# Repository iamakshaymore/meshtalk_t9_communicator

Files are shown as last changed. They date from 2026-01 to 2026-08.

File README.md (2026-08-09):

<div align="center" markdown="1">

Meshtastic Logo
<h1>Meshtastic Firmware</h1>









</div>

</div>

<div align="center">
	<a href="https://meshtastic.org">Website</a>
	-
	<a href="https://meshtastic.org/docs/">Documentation</a>
</div>

## Overview

**This is a fork of the official Meshtastic firmware** with custom UI implementation currently working on:
- **Heltec WiFi LoRa 32 V3**
- **Heltec WiFi LoRa 32 V4**
- **MeshTalk T9** (Custom PCB - MESHTASTIC Build-Off 2026 Entry)

This fork adds a custom keyboard-driven UI with T9 input, LoRa network visualization, and message management capabilities using a 4x4 matrix keypad and TFT display.

### Hardware Configuration

#### Heltec V3 Custom Pin Configuration

**TFT Display (ST7789 240x320):**
- CS: GPIO 10
- DC: GPIO 11  
- RST: GPIO 12
- Backlight: GPIO 13
- SPI: VSPI (MOSI: 35, SCK: 36)

**4x4 Matrix Keypad:**
- Rows: GPIO 14, 15, 16, 17
- Cols: GPIO 4, 5, 6, 7

**Power & Battery:**
- VEXT Enable: GPIO 18 (active low)
- Battery Pin: GPIO 1 (ADC)
- ADC Channel: ADC_CHANNEL_0

#### Heltec V4 Custom Pin Configuration

**TFT Display (ST7789 240x320):**
- CS: GPIO 10
- DC: GPIO 11
- RST: GPIO 12  
- Backlight: GPIO 13
- SPI: VSPI (MOSI: 11, SCK: 14)

**4x4 Matrix Keypad:**
- Rows: GPIO 4, 5, 6, 7
- Cols: GPIO 15, 16, 17, 18

**Power & Battery:**
- VEXT Enable: GPIO 36 (active high, always on - powers GC1109 LDO)
- Battery Pin: GPIO 1 (ADC)
- ADC Channel: ADC_CHANNEL_0

#### MeshTalk T9 Custom Pin Configuration (MESHTASTIC Build-Off 2026 🏆)

**Hardware Platform:**
- **MCU:** ESP32-S3-WROOM-1-N16R8 (16MB Flash, 8MB PSRAM)
- **LoRa Module:** Seeed Wio-SX1262
- **Display:** ST7789 TFT (240x320) via LovyanGFX
- **Input:** 4x4 Matrix Keypad
- **Form Factor:** Custom PCB design with integrated components

**LoRa Configuration (Wio-SX1262):**
- MISO: GPIO 11
- MOSI: GPIO 12
- SCK: GPIO 13
- CS: GPIO 21
- Reset: GPIO 14
- DIO1: GPIO 9
- BUSY: GPIO 10
- RF Switch: DIO2 controlled
- TCXO: 1.8V

**Power & Battery:**
- Battery ADC: GPIO 8 (ADC_CHANNEL_7)
- ADC Control: GPIO 47 (enable/disable to save power)
- ADC Multiplier: 4.9 (390kΩ/10kΩ voltage divider)
- ADC Attenuation: 2.5dB
- Boot Button: GPIO 0 (hardware pull-up)

**Flash & Memory:**
- 16MB Flash (QIO mode, 80MHz)
- 8MB Octal SPI PSRAM (QIO OPI mode)
- Custom 16MB partition scheme

**Project Links:**
- 📁 Hardware Design: `meshtastic-build-off-2026/Hardware/meshtalk_t9/`
- 🎬 Demo Video: [YouTube](https://www.youtube.com/watch?v=elmYMMCQKS4)
- 📸 Photos & Schematics: `meshtastic-build-off-2026/Demo/`

### Features

- Custom T9 text input system for efficient messaging
- LoRa network node visualization with signal strength indicators
- Message management (send/receive/view history)
- Direct messaging and channel messaging support
- Favorites management
- Battery monitoring and power management
- Bluetooth disabled for reduced power consumption

## MESHTASTIC Build-Off 2026 Status 🏆

This project is my entry for the **MESHTASTIC Build-Off 2026** competition featuring the **MeshTalk T9** - a custom hardware device with integrated display and keypad.

### Phase 1: Custom PCB Design ✅ **COMPLETE**
- ✅ Designed custom PCB using **ESP32-S3-WROOM-1-N16R8** (16MB Flash, 8MB PSRAM)
- ✅ Integrated **Seeed Wio-SX1262** LoRa module
- ✅ Optimized board layout with RF considerations
- ✅ Integrated keypad matrix and display connections on-board
- ✅ Implemented power management with battery charging circuitry
- ✅ PCB manufactured and assembled successfully

### Phase 2: Firmware Adaptation ✅ **COMPLETE**
- ✅ Ported custom UI module to MeshTalk T9 hardware
- ✅ Updated pin configurations for custom PCB (`variants/esp32s3/meshtalk_t9/`)
- ✅ Configured SX1262 LoRa radio with proper RF switching
- ✅ Implemented battery monitoring with ADC control for power savings
- ✅ Created custom variant configuration with 16MB partition scheme
- ✅ Device boots and runs Meshtastic firmware successfully

### Phase 3: Testing & Validation ✅ **COMPLETE**
- ✅ Extensive testing similar to Heltec V3/V4 validation
- ✅ Range testing and mesh network performance benchmarks
- ✅ Power consumption analysis and optimization
- ✅ UI/UX testing with physical hardware
- ✅ Field testing in real-world scenarios
- ✅ Documentation and competition submission preparation

## Building the Firmware

### For Heltec V3 Custom
```bash
platformio run -e heltec-v3-custom
platformio run -e heltec-v3-custom -t upload
```

### For Heltec V4 Custom
```bash
platformio run -e heltec-v4-custom
platformio run -e heltec-v4-custom -t upload
```

### For MeshTalk T9 (Build-Off 2026 Entry)
```bash
# Build firmware
platformio run -e meshtalk-t9

# Upload to device
platformio run -e meshtalk-t9 -t upload --upload-port /dev/cu.usbmodem101

# Erase flash and upload (for first-time flash or troubleshooting)
platformio run -e meshtalk-t9 -t erase_upload

# Monitor serial output
platformio device monitor -p /dev/cu.usbmodem101
```

### Get Started

- 🔧 **[Original Meshtastic Firmware](https://github.com/meshtastic/firmware)** – Upstream repository
- 📖 **[Building Instructions](https://meshtastic.org/docs/development/firmware/build)** - Learn how to compile the firmware from source.
- ⚡ **[Flashing Instructions](https://meshtastic.org/docs/getting-started/flashing-firmware/)** - Install or update the firmware on your device.

Join the Meshtastic community and help improve the project! 🚀

## Stats

Repobeats analytics image

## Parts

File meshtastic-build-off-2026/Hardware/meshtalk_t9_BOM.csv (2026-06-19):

Reference | Qty | Value | DNP | Exclude from BOM | Exclude from Board | Footprint | Datasheet | Manufacturer | Description | MPN
C2 | 1 | 0.1uF |  |  |  | Capacitor_SMD:C_0805_2012Metric | ~ | YAGEO | Unpolarized capacitor, small symbol | CC0805KRX7R9BB104
C3 | 1 | 0.1uF |  |  |  | Capacitor_SMD:C_0805_2012Metric | ~ | YAGEO | Unpolarized capacitor, small symbol | CC0805KRX7R9BB104
C6 | 1 | 0.1uF |  |  |  | Capacitor_SMD:C_0805_2012Metric | ~ | YAGEO | Unpolarized capacitor, small symbol | CC0805KRX7R9BB104
R9 | 1 | 470 |  |  |  | Resistor_SMD:R_0805_2012Metric | ~ | YAGEO | Resistor, small symbol | RC0805FR-07470RL
R7 | 1 | 2k |  |  |  | Resistor_SMD:R_0805_2012Metric | ~ | YAGEO | Resistor, small symbol | RC0805FR-072KL
R2 | 1 | 5.1k |  |  |  | Resistor_SMD:R_0805_2012Metric | ~ | YAGEO | Resistor, small symbol | RC0805FR-075K1L
R3 | 1 | 5.1k |  |  |  | Resistor_SMD:R_0805_2012Metric | ~ | YAGEO | Resistor, small symbol | RC0805FR-075K1L
R1 | 1 | 10k |  |  |  | Resistor_SMD:R_0805_2012Metric | ~ | YAGEO | Resistor, small symbol | RC0805FR-0710KL
R10 | 1 | 10k |  |  |  | Resistor_SMD:R_0805_2012Metric | ~ | YAGEO | Resistor, small symbol | RC0805FR-0710KL
R11 | 1 | 10k |  |  |  | Resistor_SMD:R_0805_2012Metric | ~ | YAGEO | Resistor, small symbol | RC0805FR-0710KL
R4 | 1 | 100k |  |  |  | Resistor_SMD:R_0805_2012Metric | ~ | YAGEO | Resistor, small symbol | RC0805FR-07100KL
R6 | 1 | 100k |  |  |  | Resistor_SMD:R_0805_2012Metric | ~ | YAGEO | Resistor, small symbol | RC0805FR-07100KL
R8 | 1 | 100k |  |  |  | Resistor_SMD:R_0805_2012Metric | ~ | YAGEO | Resistor, small symbol | RC0805FR-07100KL
R5 | 1 | 390k |  |  |  | Resistor_SMD:R_0805_2012Metric | ~ | YAGEO | Resistor, small symbol | RC0805FR-07390KL
C1 | 1 | 10uF 16V X5R |  |  |  | Capacitor_SMD:C_0805_2012Metric | ~ | Samsung | Unpolarized capacitor, small symbol | CL21A106KOQNNNE
C4 | 1 | 10uF 16V X5R |  |  |  | Capacitor_SMD:C_0805_2012Metric | ~ | Samsung | Unpolarized capacitor, small symbol | CL21A106KOQNNNE
C5 | 1 | 10uF 16V X5R |  |  |  | Capacitor_SMD:C_0805_2012Metric | ~ | Samsung | Unpolarized capacitor, small symbol | CL21A106KOQNNNE
Q2 | 1 | 2N7002 |  |  |  | Package_TO_SOT_SMD:SOT-23 | https://www.onsemi.com/pub/Collateral/NDS7002A-D.PDF | Nexperia | 0.115A Id, 60V Vds, N-Channel MOSFET, SOT-23 | 2N7002,215
U5 | 1 | AP7361C-33E |  |  |  | Package_TO_SOT_SMD:SOT-223-3_TabPin2 | https://www.diodes.com/assets/Datasheets/AP7361C.pdf | Diodes Inc | 1A Low Dropout regulator, positive, 3.3V fixed output, SOT-223 | AP7361C-33E-13
J2 | 1 | Conn_01x02_Socket |  |  |  | Connector_Molex:Molex_PicoBlade_53261-0271_1x02-1MP_P1.25mm_Horizontal | ~ | Molex | Generic connector, single row, 01x02, script generated | 53261-0271
D1 | 1 | D_Schottky |  |  |  | Diode_SMD:D_SOD-123 | ~ | onsemi | Schottky diode | MBR0520LT1G
U1 | 1 | ESP32-S3-WROOM-1 |  |  |  | RF_Module:ESP32-S3-WROOM-1 | https://www.espressif.com/sites/default/files/documentation/esp32-s3-wroom-1_wroom-1u_datasheet_en.pdf | Espressif | RF Module, ESP32-S3 SoC, Wi-Fi 802.11b/g/n, Bluetooth, BLE, 32-bit, 3.3V, onboard antenna, SMD | ESP32-S3-WROOM-1-N16R16VA
D2 | 1 | LED |  |  |  | LED_SMD:LED_0805_2012Metric | ~ | Everlight | Light emitting diode | 17-215/GHC-YR1S2/3T
U3 | 1 | MCP73831-2-MC |  |  |  | Package_DFN_QFN:DFN-8-1EP_3x2mm_P0.5mm_EP1.7x1.4mm | http://ww1.microchip.com/downloads/en/DeviceDoc/20001984g.pdf | Microchip | Single cell, Li-Ion/Li-Po charge management controller, 4.20V, Tri-State Status Output, in DFN-8 package | MCP73831T-2ACI/MC
H1 | 1 | MountingHole |  | Excluded from BOM |  | MountingHole:MountingHole_2.2mm_M2 | ~ |  | Mounting Hole without connection
H2 | 1 | MountingHole |  | Excluded from BOM |  | MountingHole:MountingHole_2.2mm_M2 | ~ |  | Mounting Hole without connection
H3 | 1 | MountingHole |  | Excluded from BOM |  | MountingHole:MountingHole_2.2mm_M2 | ~ |  | Mounting Hole without connection
H4 | 1 | MountingHole |  | Excluded from BOM |  | MountingHole:MountingHole_2.2mm_M2 | ~ |  | Mounting Hole without connection
Q1 | 1 | Q_PMOS_GSD |  |  |  | Package_TO_SOT_SMD:SOT-23 | ~ | Alpha & Omega | P-MOSFET transistor, gate/source/drain | AO3401A
Q3 | 1 | Q_PMOS_GSD |  |  |  | Package_TO_SOT_SMD:SOT-23 | ~ | Alpha & Omega | P-MOSFET transistor, gate/source/drain | AO3401A
SW1 | 1 | SW_Push |  |  |  | Button_Switch_SMD:SW_Push_1P1T_NO_CK_KMR2 | ~ | HROparts | Push button switch, generic, two pins | KMR221G LFS
SW2 | 1 | SW_Push |  |  |  | Button_Switch_SMD:SW_SPST_Omron_B3FS-100xP | ~ | Omron | Push button switch, generic, two pins | B3FS-1002P
SW3 | 1 | SW_Push |  |  |  | Button_Switch_SMD:SW_SPST_Omron_B3FS-100xP | ~ | Omron | Push button switch, generic, two pins | B3FS-1002P
SW4 | 1 | SW_Push |  |  |  | Button_Switch_SMD:SW_SPST_Omron_B3FS-100xP | ~ | Omron | Push button switch, generic, two pins | B3FS-1002P
SW5 | 1 | SW_Push |  |  |  | Button_Switch_SMD:SW_SPST_Omron_B3FS-100xP | ~ | Omron | Push button switch, generic, two pins | B3FS-1002P
SW6 | 1 | SW_Push |  |  |  | Button_Switch_SMD:SW_SPST_Omron_B3FS-100xP | ~ | Omron | Push button switch, generic, two pins | B3FS-1002P
SW7 | 1 | SW_Push |  |  |  | Button_Switch_SMD:SW_SPST_Omron_B3FS-100xP | ~ | Omron | Push button switch, generic, two pins | B3FS-1002P
SW8 | 1 | SW_Push |  |  |  | Button_Switch_SMD:SW_SPST_Omron_B3FS-100xP | ~ | Omron | Push button switch, generic, two pins | B3FS-1002P
SW9 | 1 | SW_Push |  |  |  | Button_Switch_SMD:SW_SPST_Omron_B3FS-100xP | ~ | Omron | Push button switch, generic, two pins | B3FS-1002P
SW10 | 1 | SW_Push |  |  |  | Button_Switch_SMD:SW_SPST_Omron_B3FS-100xP | ~ | Omron | Push button switch, generic, two pins | B3FS-1002P
SW11 | 1 | SW_Push |  |  |  | Button_Switch_SMD:SW_SPST_Omron_B3FS-100xP | ~ | Omron | Push button switch, generic, two pins | B3FS-1002P
SW12 | 1 | SW_Push |  |  |  | Button_Switch_SMD:SW_SPST_Omron_B3FS-100xP | ~ | Omron | Push button switch, generic, two pins | B3FS-1002P
SW13 | 1 | SW_Push |  |  |  | Button_Switch_SMD:SW_SPST_Omron_B3FS-100xP | ~ | Omron | Push button switch, generic, two pins | B3FS-1002P
SW14 | 1 | SW_Push |  |  |  | Button_Switch_SMD:SW_SPST_Omron_B3FS-100xP | ~ | Omron | Push button switch, generic, two pins | B3FS-1002P
SW15 | 1 | SW_Push |  |  |  | Button_Switch_SMD:SW_SPST_Omron_B3FS-100xP | ~ | Omron | Push button switch, generic, two pins | B3FS-1002P
SW16 | 1 | SW_Push |  |  |  | Button_Switch_SMD:SW_SPST_Omron_B3FS-100xP | ~ | Omron | Push button switch, generic, two pins | B3FS-1002P
SW17 | 1 | SW_Push |  |  |  | Button_Switch_SMD:SW_SPST_Omron_B3FS-100xP | ~ | Omron | Push button switch, generic, two pins | B3FS-1002P
SW18 | 1 | SW_Push |  |  |  | Button_Switch_SMD:SW_Push_1P1T_NO_CK_KMR2 | ~ | HROparts | Push button switch, generic, two pins | KMR221G LFS
TP1 | 1 | TestPoint |  | Excluded from BOM |  | TestPoint:TestPoint_Pad_D1.0mm | ~ |  | test point
TP2 | 1 | TestPoint |  | Excluded from BOM |  | TestPoint:TestPoint_Pad_D1.0mm | ~ |  | test point
TP3 | 1 | TestPoint |  | Excluded from BOM |  | TestPoint:TestPoint_Pad_D1.0mm | ~ |  | test point
TP4 | 1 | TestPoint |  | Excluded from BOM |  | TestPoint:TestPoint_Pad_D1.0mm | ~ |  | test point
TP5 | 1 | TestPoint |  | Excluded from BOM |  | TestPoint:TestPoint_Pad_D1.0mm | ~ |  | test point
TP6 | 1 | TestPoint |  | Excluded from BOM |  | TestPoint:TestPoint_Pad_D1.0mm | ~ |  | test point
TP7 | 1 | TestPoint |  | Excluded from BOM |  | TestPoint:TestPoint_Pad_D1.0mm | ~ |  | test point
TP8 | 1 | TestPoint |  | Excluded from BOM |  | TestPoint:TestPoint_Pad_D1.0mm | ~ |  | test point
J1 | 1 | USB_C_Receptacle_USB2.0_16P |  |  |  | Connector_USB:USB_C_Receptacle_HRO_TYPE-C-31-M-12 | https://www.usb.org/sites/default/files/documents/usb_type-c.zip | HROparts | USB 2.0-only 16P Type-C Receptacle connector | TYPE-C-31-M-12
U2 | 1 | USBLC6-2SC6 |  |  |  | Package_TO_SOT_SMD:SOT-23-6 | https://www.st.com/resource/en/datasheet/usblc6-2.pdf | STMicroelectronics | Very low capacitance ESD protection diode, 2 data-line, SOT-23-6 | USBLC6-2SC6
U4 | 1 | Wio-SX1262 |  |  |  | Module:Wio SX1262 |  | SenseCAP |  | Wio-SX1262

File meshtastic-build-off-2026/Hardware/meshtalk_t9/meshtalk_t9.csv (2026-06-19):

Id | Designator | Footprint | Quantity | Designation | Supplier and ref
1 | R6,R4,R8 | R_0805_2012Metric | 3 | 100k
2 | U3 | DFN-8-1EP_3x2mm_P0.5mm_EP1.7x1.4mm | 1 | MCP73831-2-MC
3 | J1 | USB_C_Receptacle_HRO_TYPE-C-31-M-12 | 1 | USB_C_Receptacle_USB2.0_16P
4 | U2 | SOT-23-5 | 1 | AP2112K-3.3
5 | U4 | Wio SX1262 | 1 | Wio-SX1262
6 | R7 | R_0805_2012Metric | 1 | 2k
7 | SW1,SW3,SW14,SW12,SW9,SW2,SW17,SW13,SW10,SW7,SW16,SW6,SW8,SW4,SW11,SW5,SW15 | SW_SPST_Omron_B3FS-100xP | 17 | SW_Push
8 | D1 | D_SOD-123 | 1 | D_Schottky
9 | R3,R2 | R_0805_2012Metric | 2 | 5.1k
10 | U1 | ESP32-S3-WROOM-1 | 1 | ESP32-S3-WROOM-1
11 | C5,C4,C1 | C_0805_2012Metric | 3 | 10uF
12 | Q1,Q3 | SOT-23 | 2 | Q_PMOS_GSD
13 | R1 | R_0805_2012Metric | 1 | 10k
14 | C6,C2 | C_0805_2012Metric | 2 | 0.1uF
15 | C3 | C_0805_2012Metric | 1 | 0.1uf
16 | Q2 | SOT-23 | 1 | 2N7002
17 | R5 | R_0805_2012Metric | 1 | 390k
18 | J2 | Molex_PicoBlade_53261-0271_1x02-1MP_P1.25mm_Horizontal | 1 | Conn_01x02_Socket
19 | TP2,TP4,TP5,TP7,TP8,TP1,TP6,TP3 | TestPoint_Pad_D1.0mm | 8 | TestPoint

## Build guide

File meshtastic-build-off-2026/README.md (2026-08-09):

# MESHTASTIC Build-Off 2026 - Hardware Design

## Project Overview

This directory contains the custom hardware design for the **MESHTASTIC Build-Off 2026** competition entry. The goal is to create a custom PCB-based Meshtastic device with integrated display and keypad interface.

## PCB Renders

<table>
<tr>
<td width="50%">

**Front**

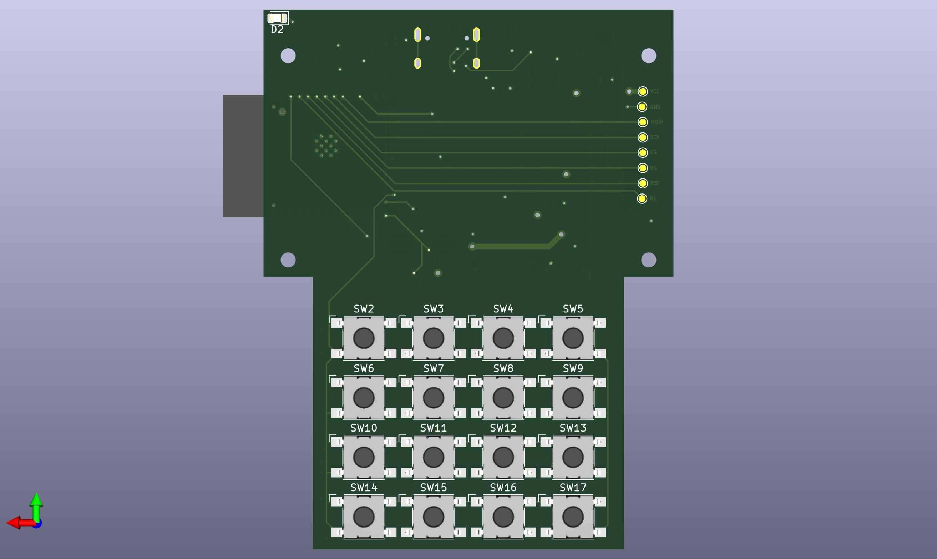
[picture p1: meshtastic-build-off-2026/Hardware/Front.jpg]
PCB Front Render


</td>
<td width="50%">

**Back**

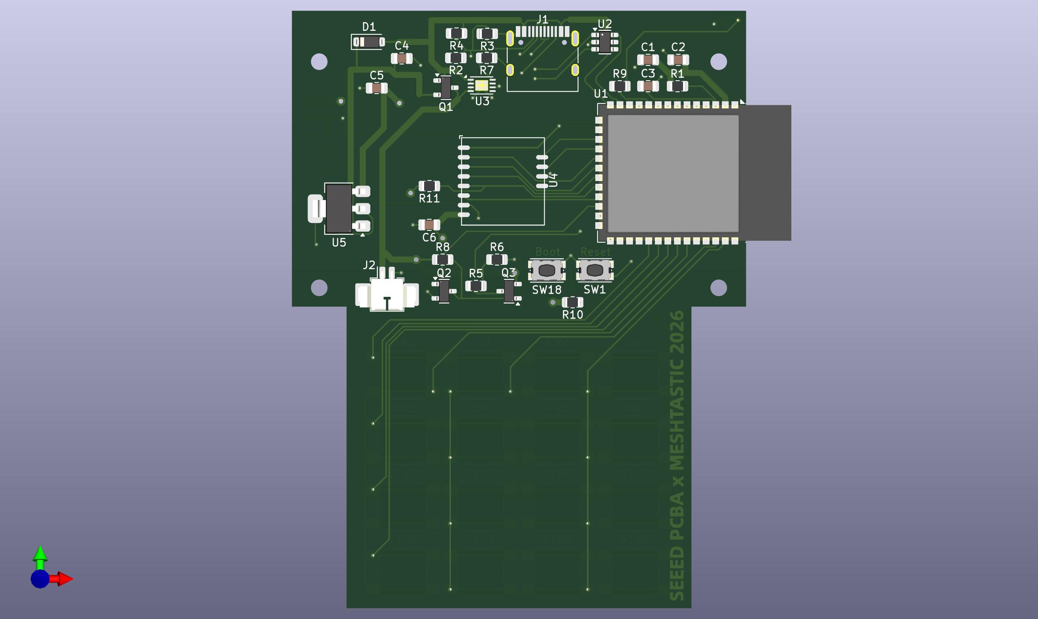
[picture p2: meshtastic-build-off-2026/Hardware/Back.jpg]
PCB Back Render


</td>
</tr>
</table>

## Schematics

<table>
<tr>
<td width="50%">

**ESP32-S3 Core**

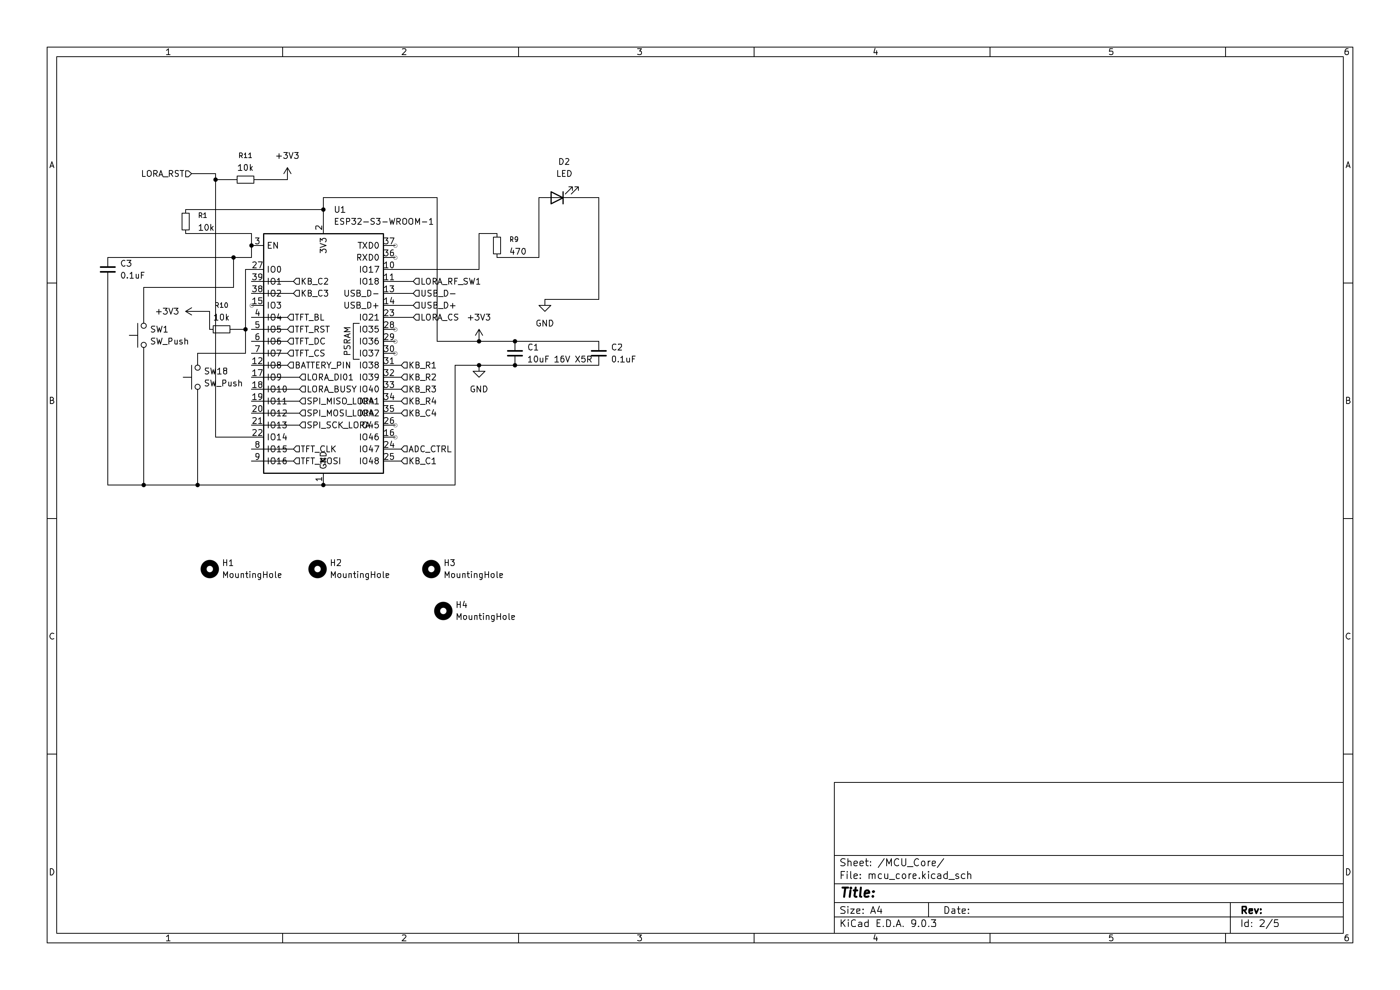
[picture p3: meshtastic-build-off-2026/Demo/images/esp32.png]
ESP32 Schematic


</td>
<td width="50%">

**LoRa Module**

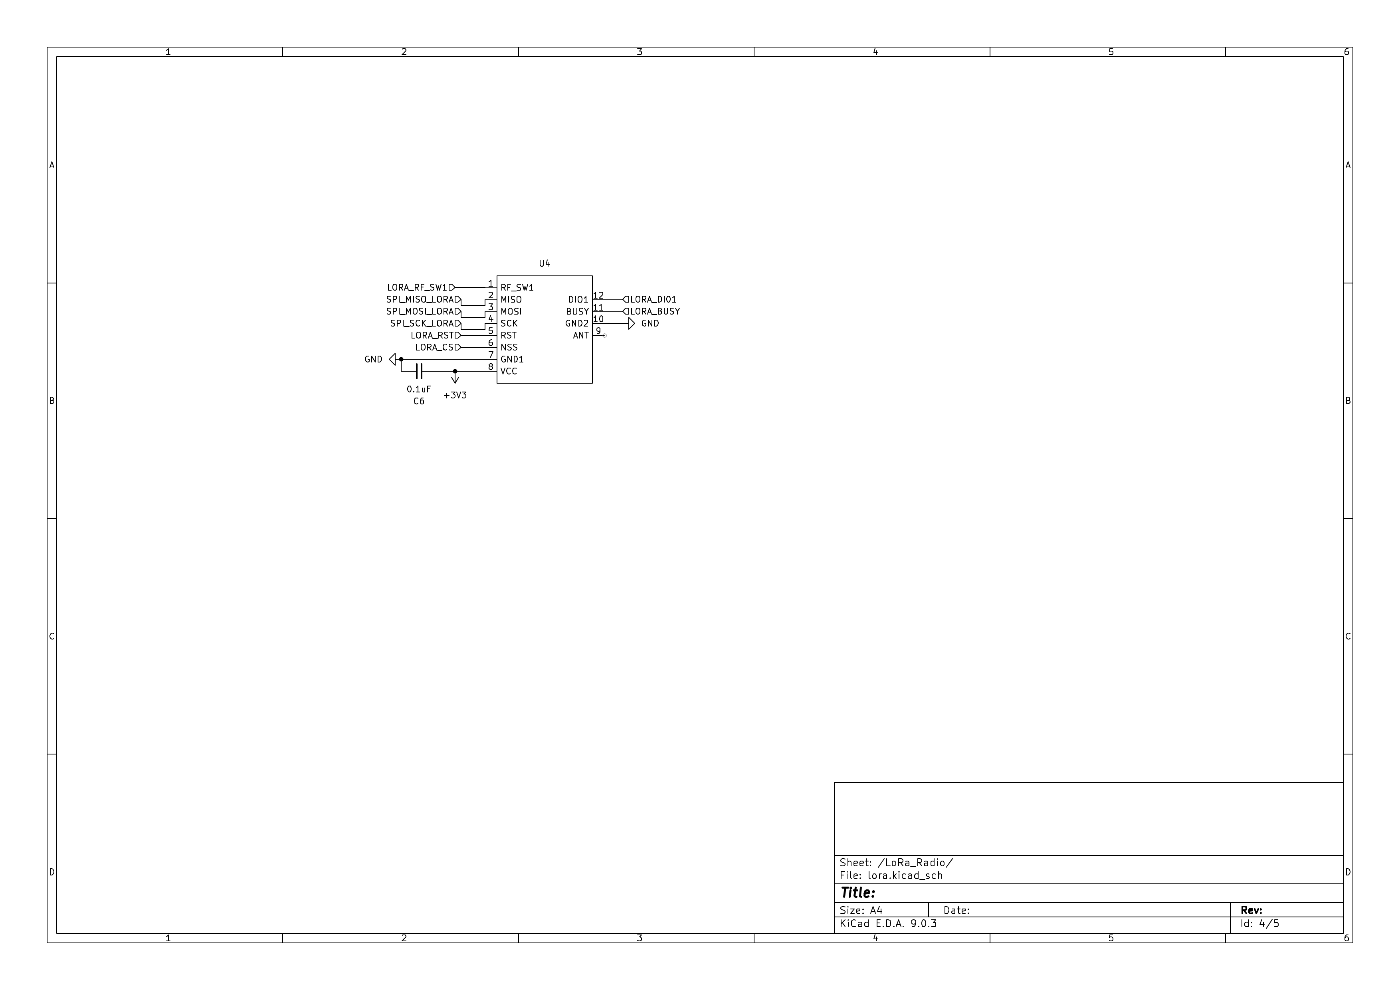
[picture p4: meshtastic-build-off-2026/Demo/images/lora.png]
LoRa Schematic


</td>
</tr>
<tr>
<td width="50%">

**User Interface**

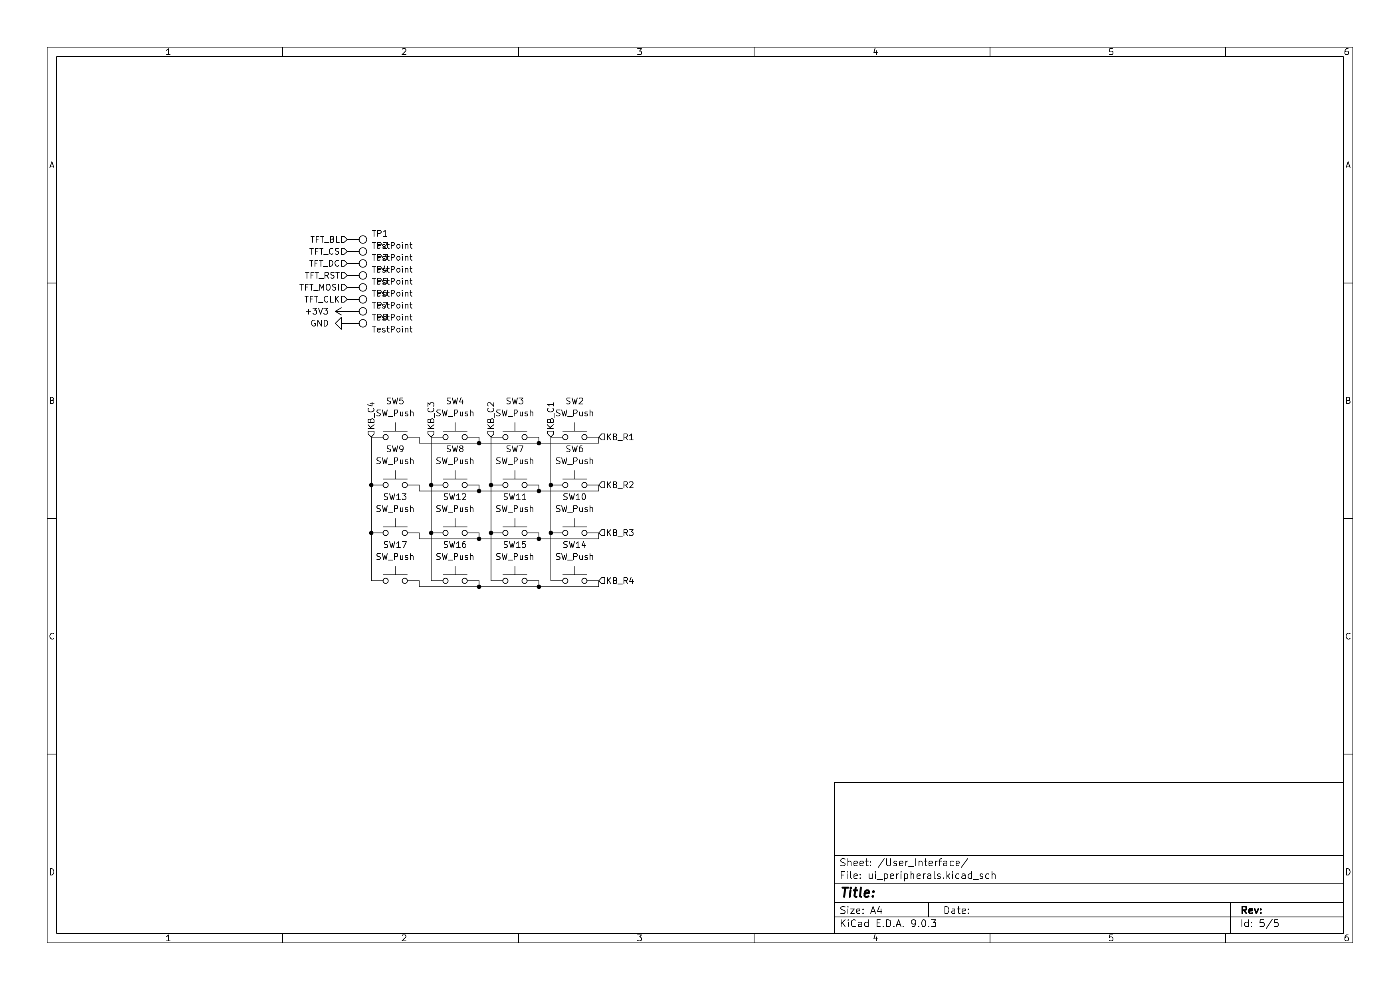
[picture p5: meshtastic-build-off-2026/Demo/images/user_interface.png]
UI Schematic


</td>
<td width="50%">

**Power Management**

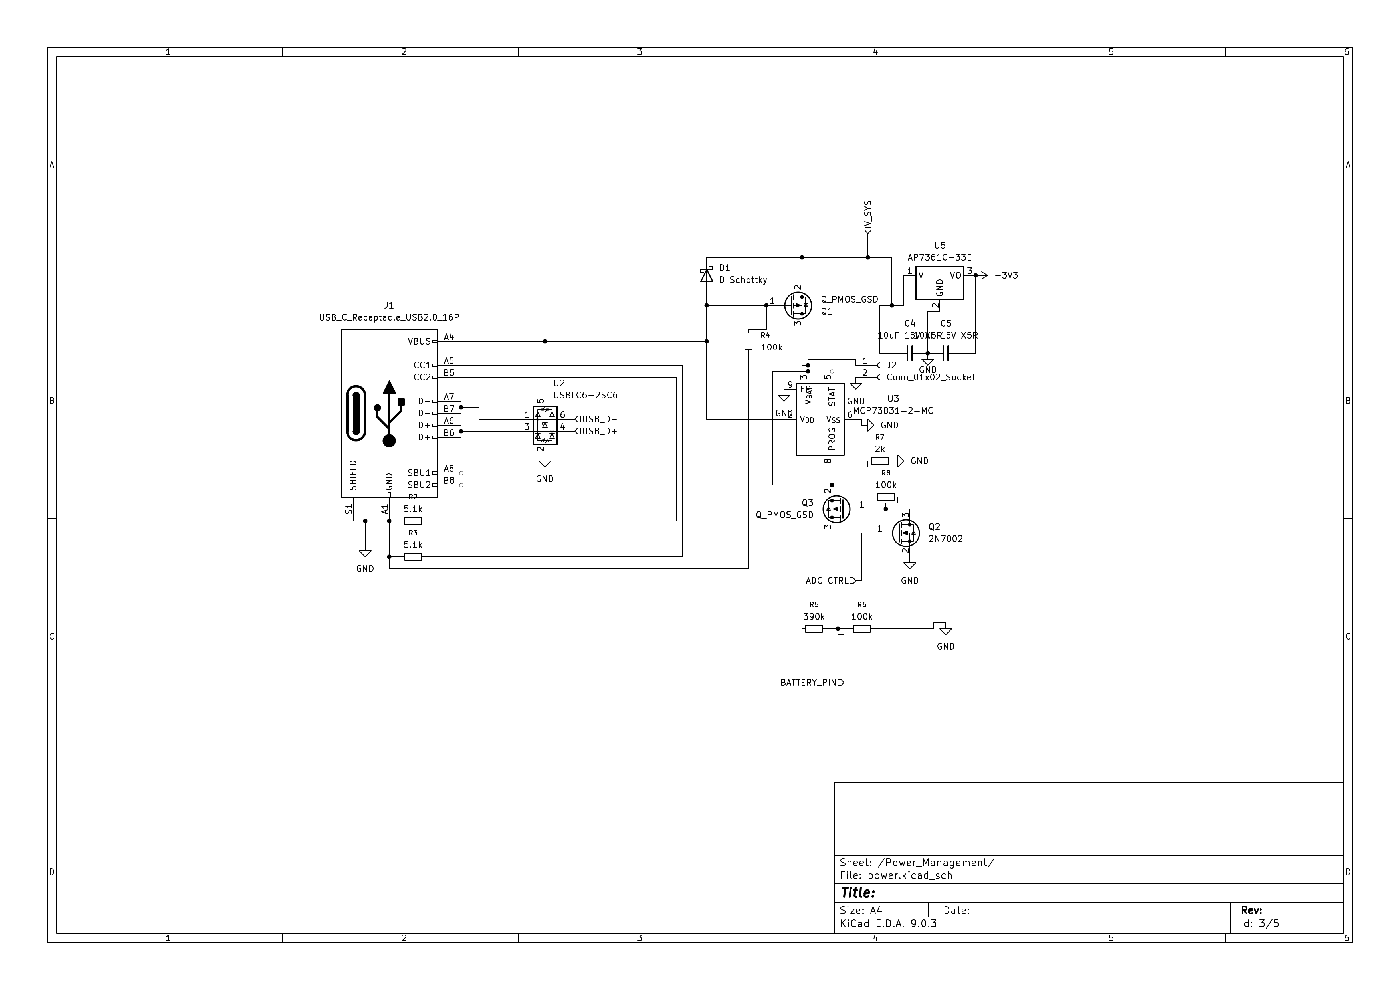
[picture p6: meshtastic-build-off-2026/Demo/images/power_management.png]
Power Schematic


</td>
</tr>
</table>

## Device Photos

### Assembled Device

<table>
<tr>
<td width="50%">

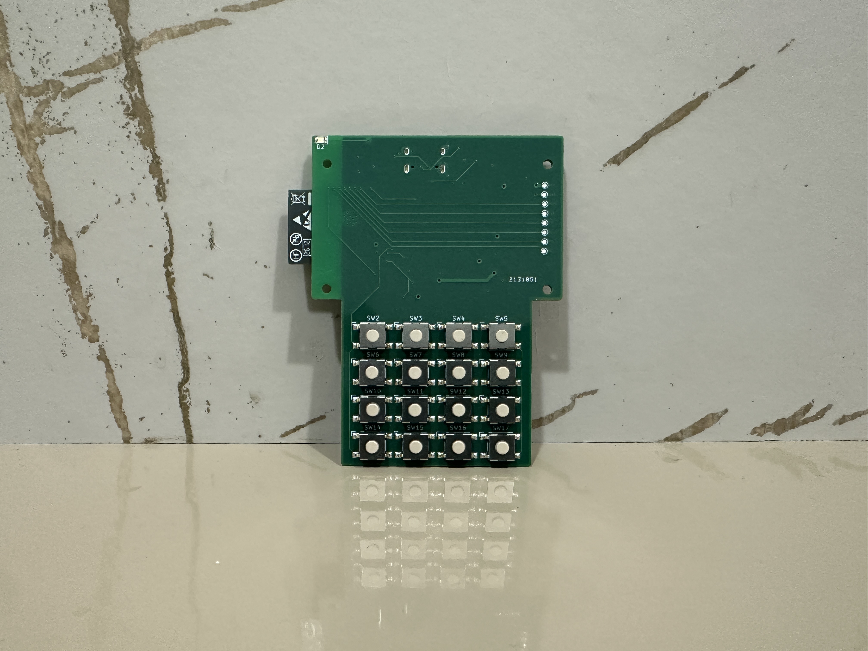
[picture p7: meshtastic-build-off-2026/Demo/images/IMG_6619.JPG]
Device Photo 1


</td>
<td width="50%">

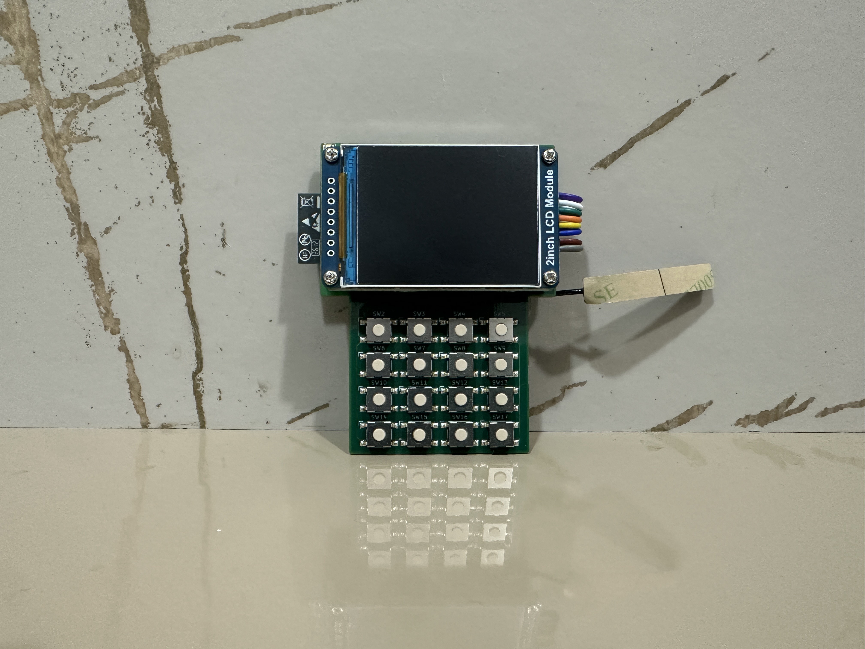
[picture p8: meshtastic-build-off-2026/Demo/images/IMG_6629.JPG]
Device Photo 2


</td>
</tr>
<tr>
<td width="50%">

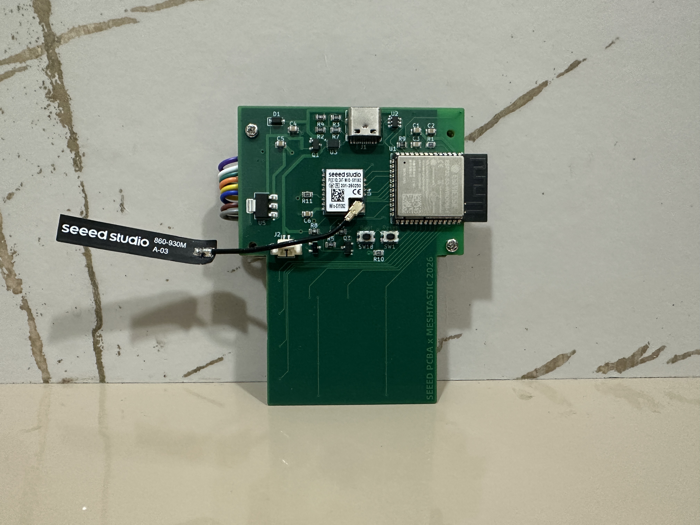
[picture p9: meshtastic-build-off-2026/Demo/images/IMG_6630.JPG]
Device Photo 3


</td>
<td width="50%">

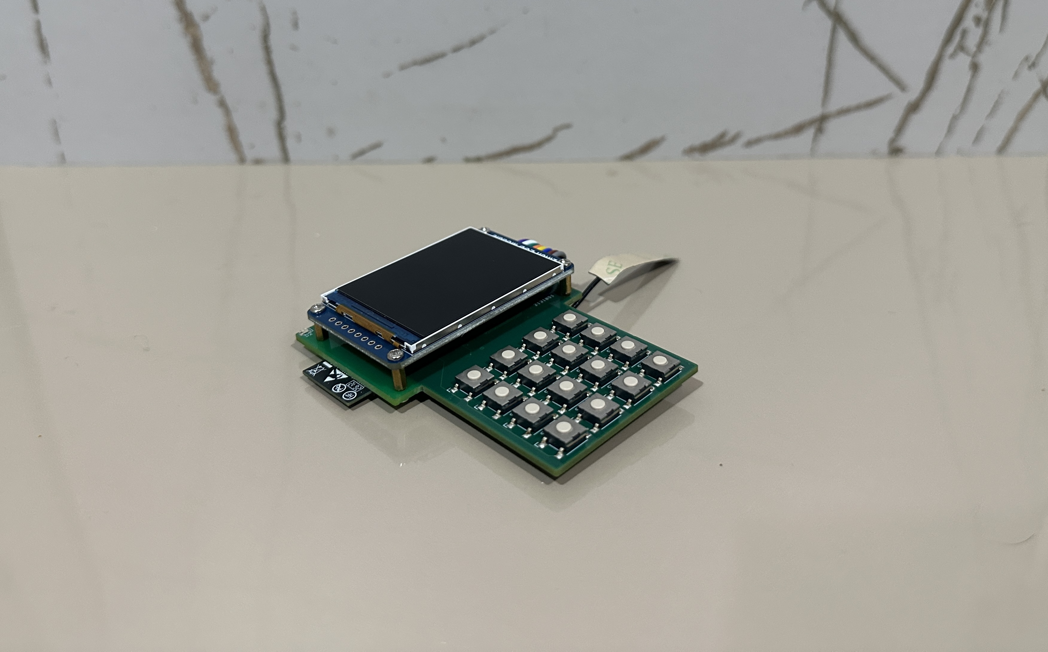
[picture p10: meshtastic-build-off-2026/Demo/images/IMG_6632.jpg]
Device Photo 4


</td>
</tr>
</table>

## Device Demonstration

### Video Walkthrough

Watch the demo video (https://www.youtube.com/watch?v=elmYMMCQKS4)

**[▶️ Click to watch the full device demonstration on Youtube](https://www.youtube.com/watch?v=elmYMMCQKS4)**

*Device demonstration showing the T9 interface, messaging, and LoRa mesh functionality*

## Competition Entry

- **Event:** MESHTASTIC Build-Off 2026
- **Category:** Custom Hardware Design
- **Project Status:** Complete - Ready for Competition

## Hardware Specifications

### Core Components

- **Microcontroller:** ESP32-S3
  - Dual-core processor
  - Built-in WiFi support
  - Low power consumption
  - Ample GPIO for peripherals

- **LoRa Module:** Wio-SX1262 Wireless Module
  - Sub-GHz LoRa transceiver
  - Long-range mesh networking capability
  - Optimized for low power operation

### Peripheral Integration

- **Display:** TFT ST7789 (240x320 pixels)
  - Custom UI with LoRa network visualization
  - Message management interface
  - Battery and signal indicators

- **Input:** 4x4 Matrix Keypad
  - T9 text input system
  - Navigation and control keys
  - Efficient one-handed operation

- **Power Management:**
  - LiPo battery support with charging circuit
  - Power monitoring and low-battery alerts
  - Optimized sleep modes

## Design Goals

1. **Integration:** Single PCB design combining all components
2. **Efficiency:** Low power consumption for extended battery life
3. **Usability:** Intuitive keypad-based interface
4. **Reliability:** Robust design suitable for outdoor/field use
5. **Compliance:** Meet MESHTASTIC Build-Off 2026 requirements

## Development Phases

### Phase 1: PCB Design ⚡ (Completed)
- [x] Schematic design (Done Jun 19, 2026)
- [x] Component selection and sourcing (Done Jun 19, 2026)
- [x] PCB layout and routing (Done Jun 19, 2026)
- [x] Power circuit design (Done Jun 19, 2026)
- [x] Antenna integration planning (Done Jun 19, 2026)

### Phase 2: Firmware Adaptation 🔧 (Completed)
- [x] Port custom UI to new hardware (Done Aug 2026)
- [x] Update pin configurations (Done Aug 2026)
- [x] Test and optimize power management (Done Aug 2026)
- [x] Create custom variant configuration (Done Aug 2026)

### Phase 3: Testing & Validation ✅ (Completed)
- [x] Prototype assembly and bring-up (Done Aug 2026)
- [x] Hardware functionality testing (Done Aug 2026)
- [x] Range and mesh network testing (Done Aug 2026)
- [x] Power consumption analysis (Done Aug 2026)
- [x] Field testing and optimization (Done Aug 2026)

## Bill of Materials (BOM)

| Order | Reference | MPN/SKU | Quantity | Unit Cost | Description |
|---|---|---|---|---|---|
| 1 | C2, C3, C6 | 302010165 | 3 | $0.06 | Capacitors |
| 2 | R9 | 301010367 | 1 | $0.01 | Resistor |
| 3 | R7 | 301010680 | 1 | $0.01 | Resistor |
| 4 | R2, R3 | 301012180 | 2 | $0.01 | Resistors |
| 5 | R1, R10, R11 | 301010361 | 3 | $0.01 | Resistors |
| 6 | R4, R6, R8 | 301010396 | 3 | $0.01 | Resistors |
| 7 | R5 | RC0805FR-07390KL | 1 | $0.23 | 390K Resistor |
| 8 | C1, C4, C5 | 302010361 | 3 | $0.05 | Capacitors |
| 9 | Q1, Q3 | 305031702 | 2 | $0.30 | Transistors |
| 10 | Q2 | 305030028 | 1 | $0.13 | Transistor |
| 11 | U5 | AP7361C-33E-13 | 1 | $2.20 | 3.3V Voltage Regulator |
| 12 | J2 | 53261-0271 | 1 | $0.98 | Connector |
| 13 | D1 | 304020028 | 1 | $0.40 | Diode |
| 14 | U1 | ESP32-S3-WROOM-1-N16R8 | 1 | $6.35 | ESP32-S3 MCU (16MB Flash, 8MB PSRAM) |
| 15 | D2 | 17-215/GHC-YR1S2/3T | 1 | $2.32 | LED |
| 16 | U3 | MCP73831T-2ACI/MC | 1 | $1.18 | Li-Po Battery Charger IC |
| 17 | SW2-SW17 | B3FS-1002P | 16 | $0.83 | Tactile Switches (4x4 Keypad) |
| 18 | SW1, SW18 | KMR221G LFS | 2 | $3.13 | Tactile Switches (Reset/Boot) |
| 19 | J1 | 320010859 | 1 | $0.75 | Connector (USB-C) |
| 20 | U2 | USBLC6-2SC6 | 1 | $2.59 | USB ESD Protection IC |
| 21 | U4 | 114993390 | 1 | $21.45 | LoRa Module/Display Module |

### Additional Components (Not in PCB Assembly)

| Component | Description | Quantity | Notes |
|---|---|---|---|
| **Display** | ST7789 TFT LCD 240x320 | 1 | 2.4" color display |
| **Battery** | Li-Po 3.7V 2000mAh | 1 | Rechargeable battery |
| **Antenna** | 868/915MHz LoRa Antenna | 1 | External SMA or U.FL |

### Cost Summary

- **PCB Components:** ~$98.88 per unit (based on 5-unit order)
- **Additional Parts:** ~$15-25 (display, battery, antenna, enclosure)
- **PCB Manufacturing:** ~$10-20 per unit (depending on quantity)
- **Assembly:** DIY or ~$30-50 professional assembly

**Total Estimated Cost per Unit:** ~$124-194

*Note: Prices based on small quantity orders (5 units). Costs decrease significantly with larger production runs.*

---

**Competition Preparation Status:** Complete  
**Last Updated:** August 2026

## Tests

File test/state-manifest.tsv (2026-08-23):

# Shared-state manifest for the native test suites.
#
# Every suite runs inside its own scratch $HOME (bin/pio-test-isolate.sh), so leftovers cannot reach
# the next suite. This file is not what makes that safe - it is what makes each suite's intent
# reviewable. A suite listed here is declaring "I mutate persisted state on purpose, and here is
# why"; a suite that is not listed is expected to leave the sandbox as it found it.
#
# The invariant behind the flags: mutation *inside* a suite is free, carrying state *across* a suite
# boundary is never permitted. No flag grants cross-suite carry - a suite that needs another suite's
# output needs an explicit fixture, not inheritance. That is the whole bug, and per-suite isolation
# keeps it impossible by construction rather than by policy.
#
# Format - three tab-separated columns, the same shape as an allowlist entry:
#
#   <suite>	<flags>	<reason>
#
# The reason column is mandatory and is reviewed on change. One central file rather than a file per
# suite, so every opt-out is visible in one diffable list and attracts review pressure; per-suite
# files hide growth. bin/run-tests.sh prints how many suites declare non-default handling, so the
# number creeping upward is visible without anyone auditing this file.
#
# Flags (space separated; the default is no entry at all):
#
#   writes=<a,b>      files this suite mutates inside its sandbox. Matched against the path relative
#                     to the scratch $HOME or just the basename, so `nodes.proto` is enough. A
#                     declared write makes the change CLEAN instead of DIRTY - the list is the
#                     documentation. A declared file that does NOT change is reported as MISSING,
#                     which catches silently-broken persistence.
#   state=per-suite   state persists across this suite's own test cases; the default is per-test.
#                     Use for persistence round-trips, migration ladders, anything where test N must
#                     observe test N-1's write. With this set, only the suite boundary is checked -
#                     per-test checking would flag every test by design.
#
# state=per-suite is the one to watch. It is legitimate, and it is also the pattern that let
# test_nodedb_blocked accumulate 198 protected nodes across its test cases. Requiring the flag makes
# that an explicit, defended choice instead of an accident of setUp().
#
# To propose entries from a real run: ./bin/run-tests.sh --write-manifest prints the lines it would
# add, for a human to paste and justify. It never applies them itself, and CI never applies them at
# all - an auto-accepted baseline is the same rot as an auto-updated snapshot.
#
# errors=<max> | <min>..<max> | <min>..   caps a suite's LOG_ERROR lines, default 100. A range, not a
# ceiling: for a fuzz suite the floor is the half that matters. test_fuzz_decode logging ~100k
# rejections is the suite working; the same suite logging none means it stopped feeding malformed
# input, and every case would still pass. Bounds are wide on purpose - they catch a path that has
# stopped running, not a drift of a few hundred lines.
#
# suite	flags	reason
test_admin_radio	writes=config.proto,module.proto,device.proto,channels.proto,nodes.proto,warm.dat,Messages_default.msgs errors=400	per-test NodeDB fixture, and the admin handlers under test persist config, channels and node metadata
test_admin_session_repro	writes=config.proto,module.proto,device.proto,channels.proto,nodes.proto	constructs a NodeDB, whose constructor persists a default set when the prefs directory is empty
test_event_channel_phone_api	writes=config.proto,module.proto,device.proto,channels.proto,nodes.proto	constructs a NodeDB, whose constructor persists a default set when the prefs directory is empty
test_event_channel_router	writes=config.proto,module.proto,device.proto,channels.proto,nodes.proto errors=200	subclasses NodeDB for the event-channel fixtures; the base constructor persists a default set when the prefs directory is empty
test_firmware_edition	writes=config.proto,module.proto,device.proto,channels.proto,nodes.proto	persists an event firmware_edition in devicestate, then reboots a NodeDB to prove a vanilla build resets it
test_fuzz_decode	errors=20000..250000	fuzzes protobuf decode; every rejection logs. A collapse to near zero means the corpus stopped reaching the decoder
test_fuzz_packets	writes=config.proto,module.proto,device.proto,channels.proto,nodes.proto,warm.dat,Messages_default.msgs errors=5000..60000	drives decode of fuzzed packets through the real NodeDB and message store
test_hop_scaling	writes=config.proto,module.proto,device.proto,channels.proto,nodes.proto	constructs a NodeDB to hold the hop-distance fixtures
test_hop_start_policy	writes=config.proto,module.proto,device.proto,channels.proto,nodes.proto	constructs a NodeDB (isFromUs needs nodeDB->getNodeNum()), whose constructor persists a default set when the prefs directory is empty
test_mesh_beacon	writes=module.proto	exercises the beacon's module-config save path
test_mesh_module	writes=config.proto,module.proto,device.proto,channels.proto,nodes.proto,warm.dat	module framework tests construct a NodeDB
test_mqtt	writes=config.proto,module.proto,device.proto,channels.proto,nodes.proto errors=1000..12000	constructs a NodeDB for node lookups in the MQTT paths
test_nexthop_routing	writes=config.proto,module.proto,device.proto,channels.proto,nodes.proto	next-hop selection reads and updates the node DB
test_nodedb_blocked	state=per-suite writes=config.proto,module.proto,device.proto,channels.proto,nodes.proto,warm.dat	saturates the DB with MAX_NUM_NODES-2 favourited nodes to test the protected cap; a later test's removeNodeByNum() persists that state, and the cap test depends on the fill from the test before it
test_nodedb_boot_recovery	state=per-suite writes=config.proto,module.proto,device.proto,channels.proto,nodes.proto	deliberate boot-recovery ladder: corrupts/deletes/restores the pref files and reboots a NodeDB per test to pin the DECODE_FAILED identity freeze, so each test observes the previous test's on-disk state
test_nodedb_identity_hygiene	writes=config.proto,module.proto,device.proto,channels.proto,nodes.proto,warm.dat,Messages_default.msgs	constructs a NodeDB; addFromContact persists the node DB after every merge, the reboot test proves the key-erasure guard survives a reload, and the should_ignore path rewrites the message store
test_nodedb_legacy_migration	writes=config.proto,module.proto,device.proto,channels.proto,nodes.proto,warm.dat	each test hand-writes a v24-format nodes.proto fixture and cold-boots a NodeDB, whose constructor persists the migrated v25 database (warm.dat via the over-cap eviction absorb)
test_nodedb_v25_roundtrip	writes=config.proto,module.proto,device.proto,channels.proto,nodes.proto,warm.dat	v25 persistence round-trips: every test saves nodes.proto and cold-boots a NodeDB whose constructor persists the default segments; warm.dat on the node-DB save cadence
test_packet_signing	writes=config.proto,module.proto,device.proto,channels.proto,nodes.proto,warm.dat errors=300	needs a NodeDB holding both peers' keys for the PKI encode/decode paths
test_phone_api_config_dump	writes=config.proto,module.proto,device.proto,channels.proto,nodes.proto	per-test NodeDB fixture backing full PhoneAPI want_config dumps; the constructor persists a default config/channel/node set in a fresh sandbox
test_pki_admin_fallback	writes=config.proto,module.proto,device.proto,channels.proto,nodes.proto	needs a NodeDB holding admin keys for the fallback paths
test_reliable_ack_matrix	writes=config.proto,module.proto,device.proto,channels.proto,nodes.proto	constructs a NodeDB (whose constructor persists a default set when the prefs directory is empty) for the sender-key lookups in the ACK/NAK matrix
test_stream_api	writes=config.proto,module.proto,device.proto,channels.proto,nodes.proto	drives real PhoneAPI handshakes, which read and persist config and the node DB
test_traceroute_nexthop	writes=config.proto,module.proto,device.proto,channels.proto,nodes.proto	traceroute route selection reads the node DB
test_traffic_management	writes=config.proto,module.proto,device.proto,channels.proto,nodes.proto,warm.dat errors=3000..12000	constructs a NodeDB for the per-node rate-limit and dedup state; test_tm_fuzz_nodenum_blitz feeds malformed payloads, and each rejection logs (measured 7985)
test_transmit_history	writes=transmit_history.dat	persistence round-trip: what it asserts is that retransmission state survives a save/load
test_warm_store	writes=warm.dat	persistence round-trip of the warm-tier snapshot, which is the tier's whole contract

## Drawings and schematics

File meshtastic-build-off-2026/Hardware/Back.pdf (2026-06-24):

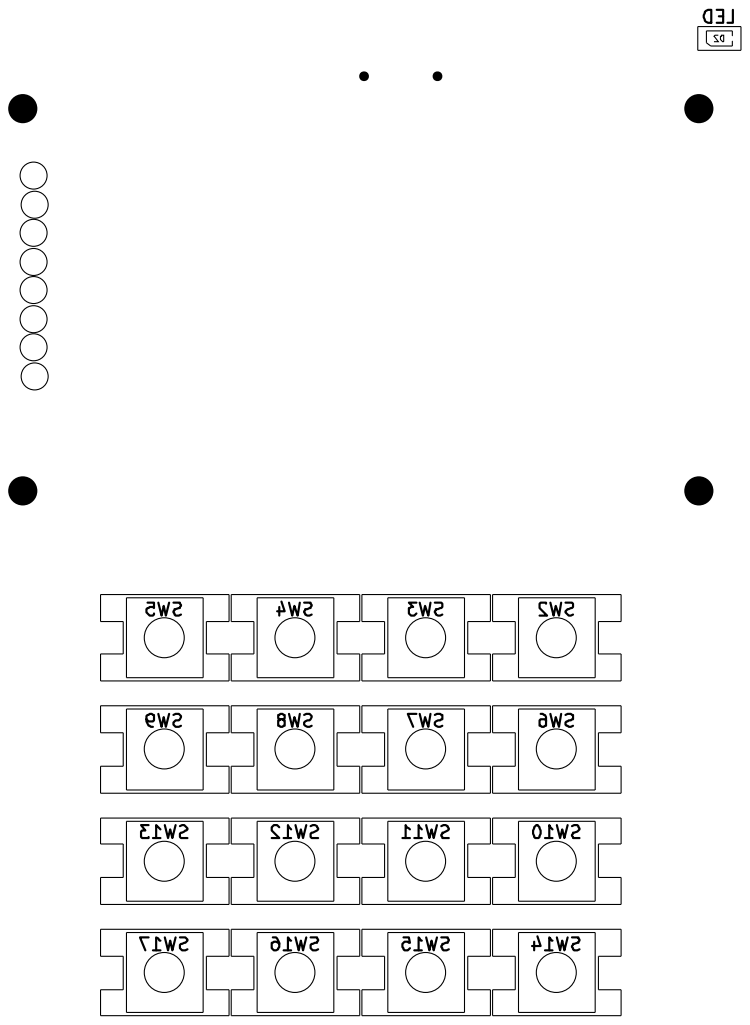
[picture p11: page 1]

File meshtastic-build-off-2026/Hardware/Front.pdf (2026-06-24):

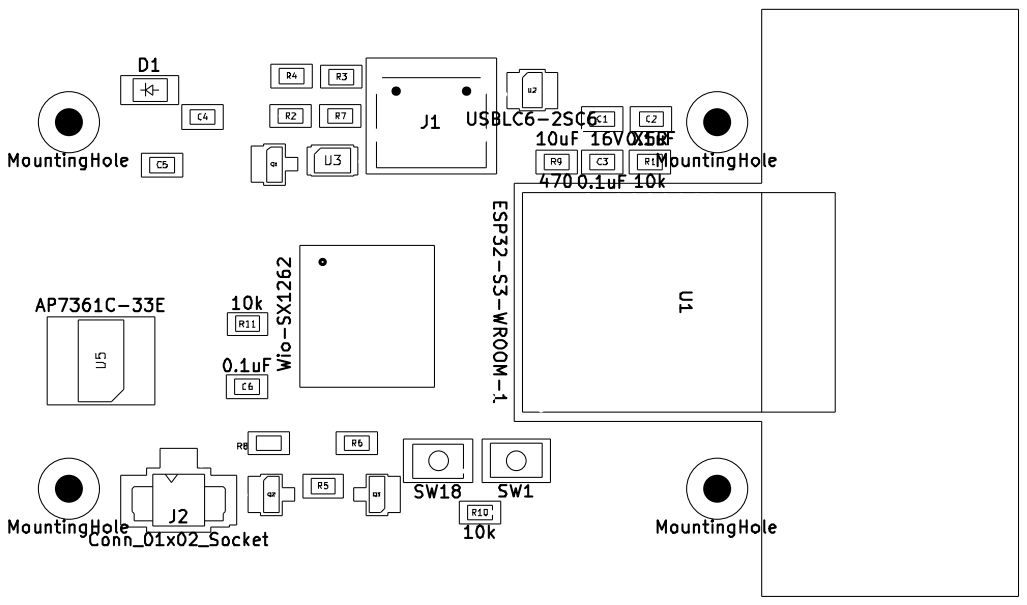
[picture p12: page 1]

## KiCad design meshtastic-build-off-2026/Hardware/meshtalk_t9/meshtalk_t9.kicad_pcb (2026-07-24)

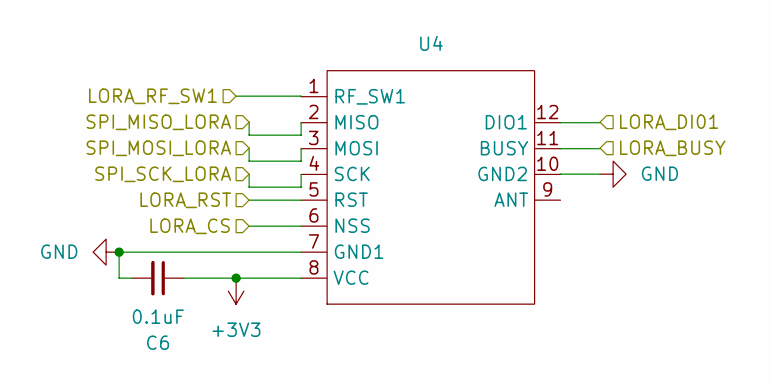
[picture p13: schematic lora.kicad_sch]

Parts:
C6: 0.1uF; C_0805_2012Metric; MPN CC0805KRX7R9BB104
U4: Wio-SX1262; Wio SX1262; MPN Wio-SX1262

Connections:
+3V3: C6.1, U4.8 (VCC); also elsewhere on the board
/LoRa_Radio/LORA_BUSY: U4.11 (BUSY); also elsewhere on the board
/LoRa_Radio/LORA_CS: U4.6 (NSS); also elsewhere on the board
/LoRa_Radio/LORA_DI01: U4.12 (DIO1); also elsewhere on the board
/LoRa_Radio/LORA_RF_SW1: U4.1 (RF_SW1); also elsewhere on the board
/LoRa_Radio/LORA_RST: U4.5 (RST); also elsewhere on the board
/LoRa_Radio/SPI_MISO_LORA: U4.2 (MISO); also elsewhere on the board
/LoRa_Radio/SPI_MOSI_LORA: U4.3 (MOSI); also elsewhere on the board
/LoRa_Radio/SPI_SCK_LORA: U4.4 (SCK); also elsewhere on the board
GND: C6.2, U4.7 (GND1), U4.10 (GND2); also elsewhere on the board

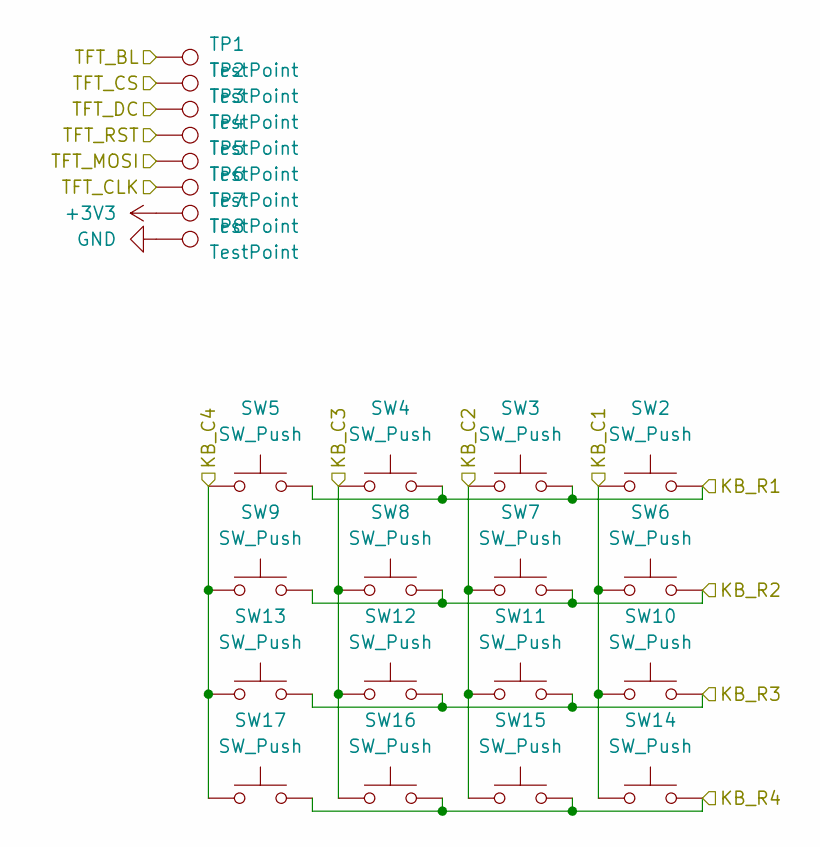
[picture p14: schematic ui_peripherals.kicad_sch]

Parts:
SW2, SW3, SW4, SW5, SW6, SW7, SW8, SW9, SW10, SW11, SW12, SW13, SW14, SW15, SW16, SW17: SW_Push; SW_SPST_Omron_B3FS-100xP; MPN B3FS-1002P
TP1, TP2, TP3, TP4, TP5, TP6, TP7, TP8: TestPoint; TestPoint_Pad_D1.0mm

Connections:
+3V3: TP7.1; also elsewhere on the board
/MCU_Core/KB_C1: SW2.2, SW6.2, SW10.2, SW14.2; also elsewhere on the board
/MCU_Core/KB_C2: SW3.2, SW7.2, SW11.2, SW15.2; also elsewhere on the board
/MCU_Core/KB_C3: SW4.2, SW8.2, SW12.2, SW16.2; also elsewhere on the board
/MCU_Core/KB_C4: SW5.2, SW9.2, SW13.2, SW17.2; also elsewhere on the board
/MCU_Core/KB_R1: SW2.1, SW3.1, SW4.1, SW5.1; also elsewhere on the board
/MCU_Core/KB_R2: SW6.1, SW7.1, SW8.1, SW9.1; also elsewhere on the board
/MCU_Core/KB_R3: SW10.1, SW11.1, SW12.1, SW13.1; also elsewhere on the board
/MCU_Core/KB_R4: SW14.1, SW15.1, SW16.1, SW17.1; also elsewhere on the board
/MCU_Core/TFT_BL: TP1.1; also elsewhere on the board
/MCU_Core/TFT_CLK: TP6.1; also elsewhere on the board
/MCU_Core/TFT_CS: TP2.1; also elsewhere on the board
/MCU_Core/TFT_DC: TP3.1; also elsewhere on the board
/MCU_Core/TFT_MOSI: TP5.1; also elsewhere on the board
/MCU_Core/TFT_RST: TP4.1; also elsewhere on the board
GND: TP8.1; also elsewhere on the board

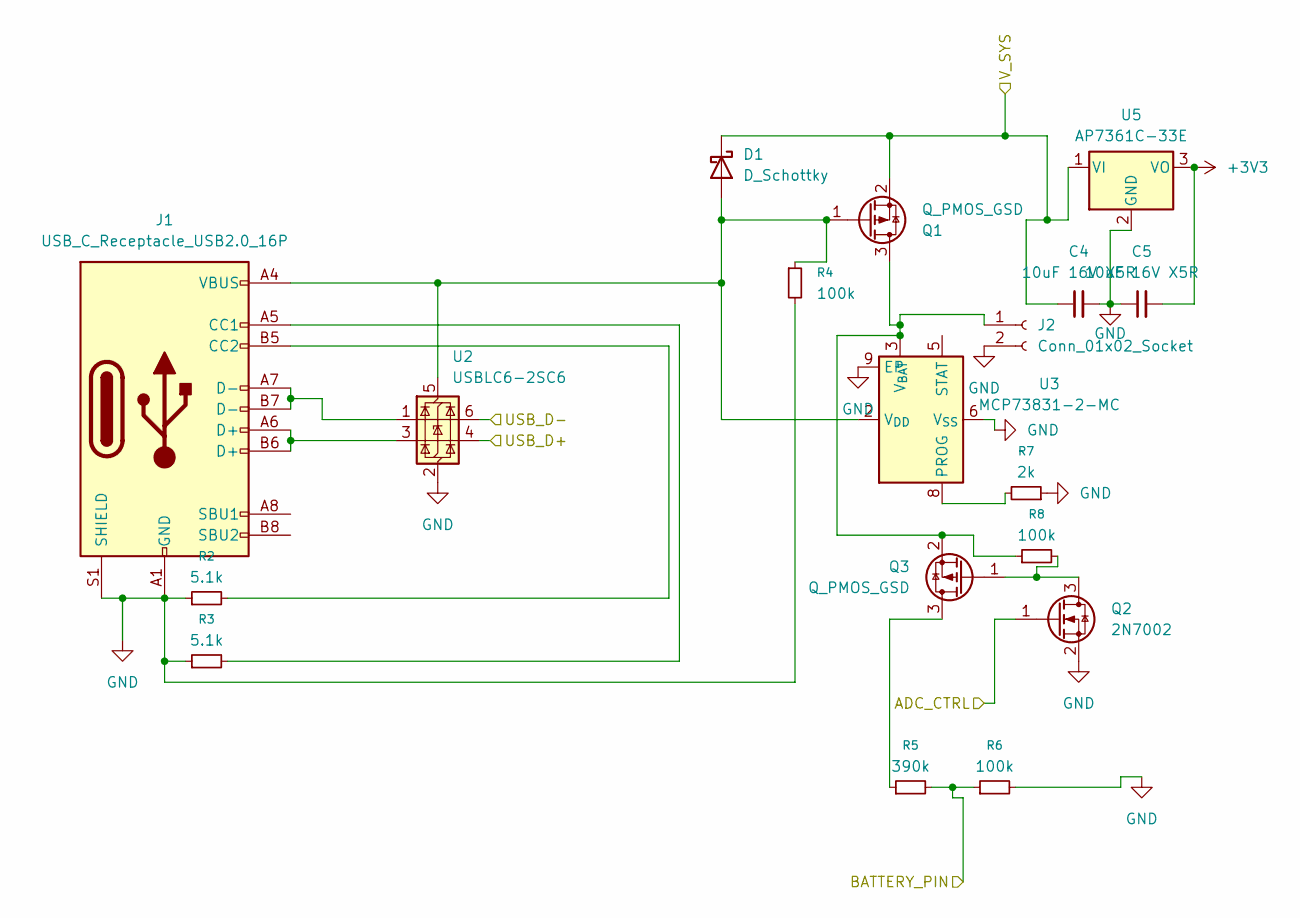
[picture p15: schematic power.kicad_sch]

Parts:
C4, C5: 10uF 16V X5R; C_0805_2012Metric; MPN CL21A106KOQNNNE
D1: D_Schottky; D_SOD-123; MPN MBR0520LT1G
J1: USB_C_Receptacle_USB2.0_16P; USB_C_Receptacle_HRO_TYPE-C-31-M-12; MPN TYPE-C-31-M-12
J2: Conn_01x02_Socket; Molex_PicoBlade_53261-0271_1x02-1MP_P1.25mm_Horizontal; MPN 53261-0271
Q1, Q3: Q_PMOS_GSD; SOT-23; MPN AO3401A
Q2: 2N7002; SOT-23; MPN 2N7002,215
R2, R3: 5.1k; R_0805_2012Metric; MPN RC0805FR-075K1L
R4, R6, R8: 100k; R_0805_2012Metric; MPN RC0805FR-07100KL
R5: 390k; R_0805_2012Metric; MPN RC0805FR-07390KL
R7: 2k; R_0805_2012Metric; MPN RC0805FR-072KL
U2: USBLC6-2SC6; SOT-23-6; MPN USBLC6-2SC6
U3: MCP73831-2-MC; DFN-8-1EP_3x2mm_P0.5mm_EP1.7x1.4mm; MPN MCP73831T-2ACI/MC
U5: AP7361C-33E; SOT-223-3_TabPin2; MPN AP7361C-33E-13

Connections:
+3V3: C5.2, U5.3 (VO); also elsewhere on the board
/MCU_Core/ADC_CTRL: Q2.1 (G); also elsewhere on the board
/MCU_Core/BATTERY_PIN: R5.2, R6.1; also elsewhere on the board
/MCU_Core/USB_D+: U2.4 (I/O2); also elsewhere on the board
/MCU_Core/USB_D-: U2.6 (I/O1); also elsewhere on the board
/Power_Management/V_SYS: C4.1, D1.1 (K), Q1.2 (S), U5.1 (VI)
GND: C4.2, C5.1, J1.A1 (GND), J1.A12 (GND), J1.B1 (GND), J1.B12 (GND), J1.S1 (SHIELD), J2.2, Q2.2 (S), R2.1, R3.1, R4.2, R6.2, R7.1, U2.2 (GND), U3.6 (V_{SS}), U3.9 (EP), U5.2 (GND); also elsewhere on the board
unnamed: D1.2 (A), J1.A4 (VBUS), J1.A9 (VBUS), J1.B4 (VBUS), J1.B9 (VBUS), Q1.1 (G), R4.1, U2.5 (VBUS), U3.1 (V_{DD}), U3.2 (V_{DD})
unnamed: J1.A5 (CC1), R3.2
unnamed: J1.B5 (CC2), R2.2
unnamed: J1.A6 (D+), J1.B6 (D+), U2.3 (I/O2)
unnamed: J1.A7 (D-), J1.B7 (D-), U2.1 (I/O1)
unnamed: J2.1, Q1.3 (D), Q3.2 (S), R8.1, U3.3 (V_{BAT}), U3.4 (V_{BAT})
unnamed: Q2.3 (D), Q3.1 (G), R8.2
unnamed: Q3.3 (D), R5.1
unnamed: R7.2, U3.8 (PROG)

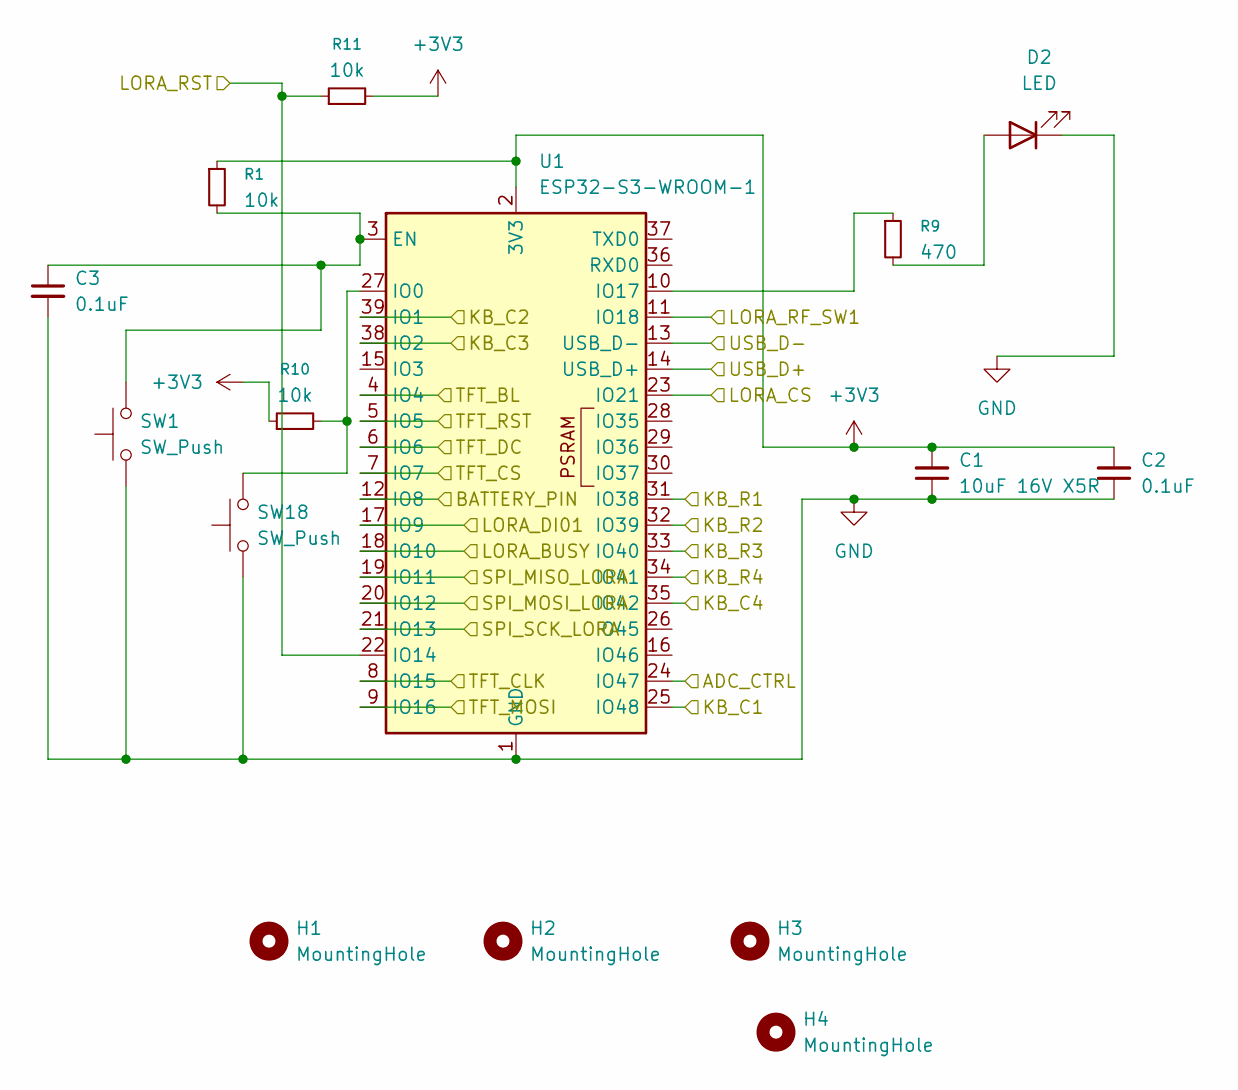
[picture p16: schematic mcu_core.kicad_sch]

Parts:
C1: 10uF 16V X5R; C_0805_2012Metric; MPN CL21A106KOQNNNE
C2, C3: 0.1uF; C_0805_2012Metric; MPN CC0805KRX7R9BB104
D2: LED; LED_0805_2012Metric; MPN 17-215/GHC-YR1S2/3T
H1, H2, H3, H4: MountingHole; MountingHole_2.2mm_M2
R1, R10, R11: 10k; R_0805_2012Metric; MPN RC0805FR-0710KL
R9: 470; R_0805_2012Metric; MPN RC0805FR-07470RL
SW1, SW18: SW_Push; SW_Push_1P1T_NO_CK_KMR2; MPN KMR221G LFS
U1: ESP32-S3-WROOM-1; MPN ESP32-S3-WROOM-1-N16R8

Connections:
+3V3: C1.2, C2.2, R1.1, R10.1, R11.2, U1.2 (3V3); also elsewhere on the board
/LoRa_Radio/LORA_BUSY: U1.18 (IO10); also elsewhere on the board
/LoRa_Radio/LORA_CS: U1.23 (IO21); also elsewhere on the board
/LoRa_Radio/LORA_DI01: U1.17 (IO9); also elsewhere on the board
/LoRa_Radio/LORA_RF_SW1: U1.11 (IO18); also elsewhere on the board
/LoRa_Radio/LORA_RST: R11.1, U1.22 (IO14); also elsewhere on the board
/LoRa_Radio/SPI_MISO_LORA: U1.19 (IO11); also elsewhere on the board
/LoRa_Radio/SPI_MOSI_LORA: U1.20 (IO12); also elsewhere on the board
/LoRa_Radio/SPI_SCK_LORA: U1.21 (IO13); also elsewhere on the board
/MCU_Core/ADC_CTRL: U1.24 (IO47); also elsewhere on the board
/MCU_Core/BATTERY_PIN: U1.12 (IO8); also elsewhere on the board
/MCU_Core/KB_C1: U1.25 (IO48); also elsewhere on the board
/MCU_Core/KB_C2: U1.39 (IO1); also elsewhere on the board
/MCU_Core/KB_C3: U1.38 (IO2); also elsewhere on the board
/MCU_Core/KB_C4: U1.35 (IO42); also elsewhere on the board
/MCU_Core/KB_R1: U1.31 (IO38); also elsewhere on the board
/MCU_Core/KB_R2: U1.32 (IO39); also elsewhere on the board
/MCU_Core/KB_R3: U1.33 (IO40); also elsewhere on the board
/MCU_Core/KB_R4: U1.34 (IO41); also elsewhere on the board
/MCU_Core/TFT_BL: U1.4 (IO4); also elsewhere on the board
/MCU_Core/TFT_CLK: U1.8 (IO15); also elsewhere on the board
/MCU_Core/TFT_CS: U1.7 (IO7); also elsewhere on the board
/MCU_Core/TFT_DC: U1.6 (IO6); also elsewhere on the board
/MCU_Core/TFT_MOSI: U1.9 (IO16); also elsewhere on the board
/MCU_Core/TFT_RST: U1.5 (IO5); also elsewhere on the board
/MCU_Core/USB_D+: U1.14 (USB_D+); also elsewhere on the board
/MCU_Core/USB_D-: U1.13 (USB_D-); also elsewhere on the board
GND: C1.1, C2.1, C3.2, D2.1 (K), SW1.1, SW18.1, U1.1 (GND), U1.40 (GND), U1.41 (GND); also elsewhere on the board
unnamed: D2.2 (A), R9.2
unnamed: C3.1, R1.2, SW1.2, U1.3 (EN)
unnamed: R10.2, SW18.2, U1.27 (IO0)
unnamed: R9.1, U1.10 (IO17)

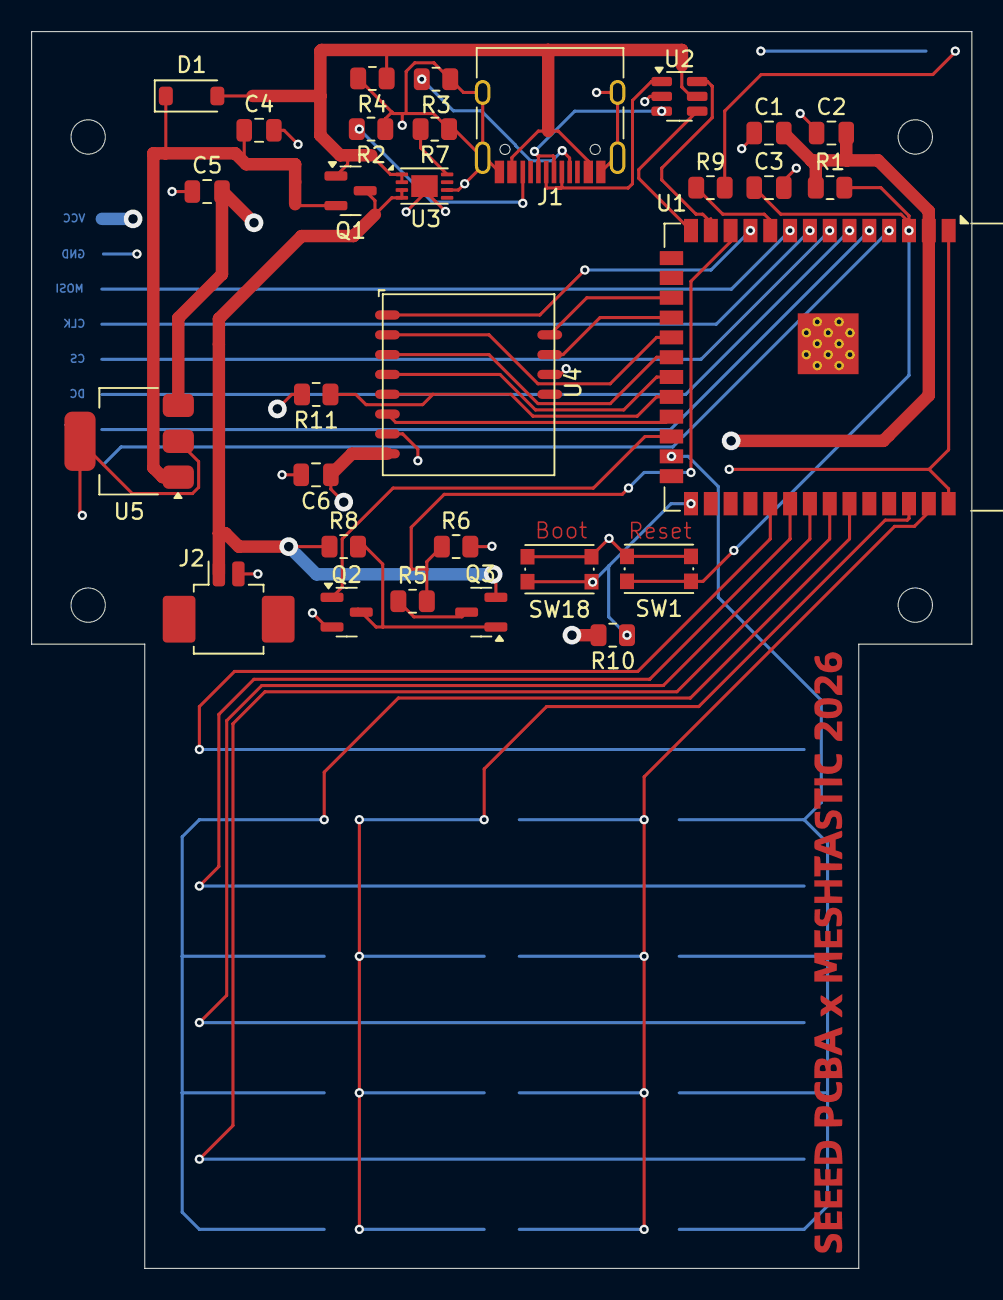
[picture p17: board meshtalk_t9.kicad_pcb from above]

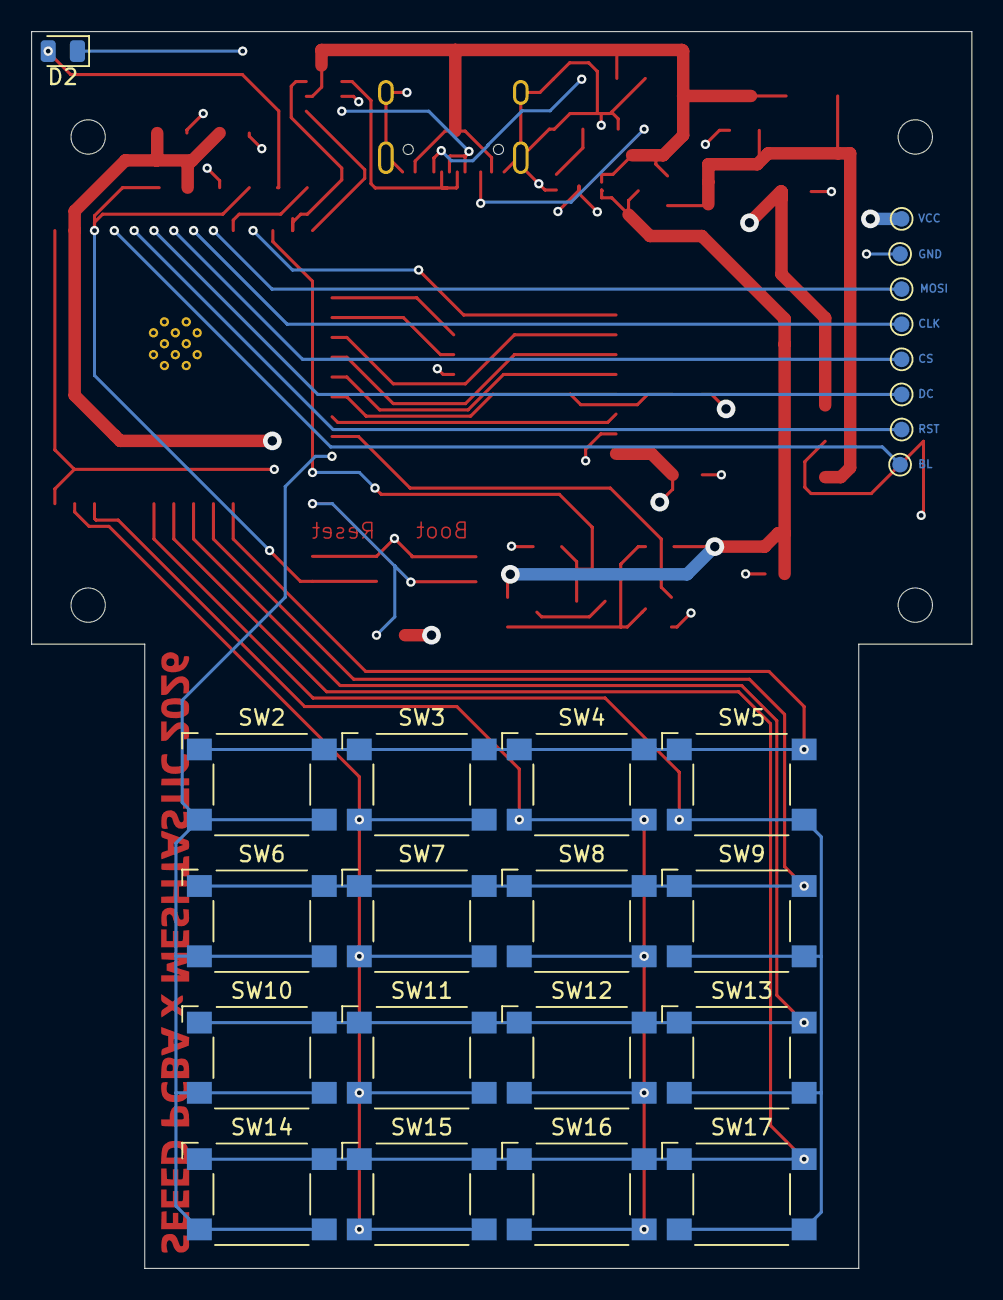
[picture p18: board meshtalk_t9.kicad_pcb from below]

Board: 4 copper layers, 60.2 x 79.2 mm, 59 parts (25 on the bottom side), 42 nets.

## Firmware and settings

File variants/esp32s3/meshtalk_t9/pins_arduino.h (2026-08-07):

#ifndef Pins_Arduino_h
#define Pins_Arduino_h

#include <stdint.h>

// CHANGED: 0x2886/0x0059 is Seeed Studio's VID/PID for the XIAO
// 0x303a/0x1001 is Espressif's standard VID/PID for custom ESP32-S3 builds
#define USB_VID 0x303a
#define USB_PID 0x1001

// CHANGED: XIAO uses 47/48 for its I2C screen connector
// No I2C devices on MeshTalk T9 — mapped to unconnected GPIOs
// to prevent any library calling Wire.begin() from clashing with TFT_BL (GPIO4)
static const uint8_t SDA = 3;
static const uint8_t SCL = 46;

// CHANGED: XIAO LoRa SPI is 8/7/9/41 (B2B connector pins)
// MeshTalk T9 LoRa SPI is on different GPIOs
static const uint8_t MISO = 11;   // SPI_MISO_LORA
static const uint8_t SCK  = 13;   // SPI_SCK_LORA
static const uint8_t MOSI = 12;   // SPI_MOSI_LORA
static const uint8_t SS   = 21;   // LORA_CS

#endif /* Pins_Arduino_h */

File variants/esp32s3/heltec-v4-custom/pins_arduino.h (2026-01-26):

/*
 * CustomUIModule - A T9 Matrix Keypad & Display Driver for Meshtastic
 * Copyright (C) 2026 Akshay Pramod More
 *
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
 * This program is distributed in the hope that it will be useful,
 * but WITHOUT ANY WARRANTY; without even the implied warranty of
 * MERCHANTABILITY or FITNESS FOR A PARTICULAR PURPOSE.  See the
 * GNU General Public License for more details.
 */

#ifndef Pins_Arduino_h
#define Pins_Arduino_h

#include <stdint.h>

#define USB_VID 0x303a
#define USB_PID 0x1001

static const uint8_t LED_BUILTIN = 35;
#define BUILTIN_LED LED_BUILTIN // backward compatibility
#define LED_BUILTIN LED_BUILTIN // allow testing #ifdef LED_BUILTIN

static const uint8_t TX = 43;
static const uint8_t RX = 44;

static const uint8_t SDA = 4;
static const uint8_t SCL = 3;

static const uint8_t SS = 8;
static const uint8_t MOSI = 10;
static const uint8_t MISO = 11;
static const uint8_t SCK = 9;

static const uint8_t A0 = 1;
static const uint8_t A1 = 2;
static const uint8_t A2 = 3;
static const uint8_t A3 = 4;
static const uint8_t A4 = 5;
static const uint8_t A5 = 6;
static const uint8_t A6 = 7;
static const uint8_t A7 = 8;
static const uint8_t A8 = 9;
static const uint8_t A9 = 10;
static const uint8_t A10 = 11;
static const uint8_t A11 = 12;
static const uint8_t A12 = 13;
static const uint8_t A13 = 14;
static const uint8_t A14 = 15;
static const uint8_t A15 = 16;
static const uint8_t A16 = 17;
static const uint8_t A17 = 18;
static const uint8_t A18 = 19;
static const uint8_t A19 = 20;

static const uint8_t T1 = 1;
static const uint8_t T2 = 2;
static const uint8_t T3 = 3;
static const uint8_t T4 = 4;
static const uint8_t T5 = 5;
static const uint8_t T6 = 6;
static const uint8_t T7 = 7;
static const uint8_t T8 = 8;
static const uint8_t T9 = 9;
static const uint8_t T10 = 10;
static const uint8_t T11 = 11;
static const uint8_t T12 = 12;
static const uint8_t T13 = 13;
static const uint8_t T14 = 14;

static const uint8_t Vext = 36;
static const uint8_t LED = 35;
static const uint8_t RST_OLED = 21;
static const uint8_t SCL_OLED = 18;
static const uint8_t SDA_OLED = 17;

static const uint8_t RST_LoRa = 12;
static const uint8_t BUSY_LoRa = 13;
static const uint8_t DIO0 = 14;

#endif /* Pins_Arduino_h */

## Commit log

2026-06-08 Working DRC
    [Untitled.kicad_pcb, Untitled.kicad_sch, lora.kicad_sch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]
2026-06-08 For Review
    [Untitled.kicad_pcb]
2026-06-09 updated PCB
    [Untitled.kicad_pcb, mcu_core.kicad_sch, ui_peripherals.kicad_sch]
2026-06-09 update power rails and vias width
    [Untitled.kicad_pcb]
2026-06-09 rename + battery % + boot btn changed to reset + fix battery chrging
    [lora.kicad_sch, mcu_core.kicad_sch, meshtalk_t9.kicad_pcb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]
2026-06-10 grb files
    [meshtalk_t9-B_Cu.gbl, meshtalk_t9-B_Mask.gbs, meshtalk_t9-B_Paste.gbp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]
2026-06-19 Replace AP2112K-3.3 with AP7361C-33E Connected LORA RF_SW1 to GPIO Added ESD Added mounting holes for display (Waveshare 2 inch) Added Boot and Reset buttons made power rails thicker added dedicated 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
    [lora.kicad_sch, mcu_core.kicad_sch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]
2026-06-19 update board images
2026-06-24 PCB Updates - Align net names Clearence for esp32 antenna
    [mcu_core.kicad_sch, meshtalk_t9.kicad_pcb, meshtalk_t9.kicad_sch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]
2026-07-24 add T9 configurations for meshtastic
    [meshtalk_t9.kicad_pcb]
2026-08-06 Fix latest upstream merge + schematics in readme
2026-08-07 Notification LED on new message + PSRAM working + LORA status fix
    [CustomUIModule.cpp, InitDisplay.cpp, pins_arduino.h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]
2026-08-08 battery % + disable serial logs
2026-08-18 Power saving

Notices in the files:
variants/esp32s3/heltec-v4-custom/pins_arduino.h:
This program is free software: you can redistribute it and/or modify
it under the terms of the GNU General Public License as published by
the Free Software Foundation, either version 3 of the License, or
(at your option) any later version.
